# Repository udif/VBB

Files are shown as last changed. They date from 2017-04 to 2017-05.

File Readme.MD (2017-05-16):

VBB - A VCC Breakout Board
==========================
This board is intended as a VCC breakout board. It supports the following features:
* A wide array of connectors: USB A, B, Micro, Mini, DC plug, Banana Plug, screw terminal.
* While GND is always connected among all connectors, D+/D-/VCC are all switchable via pins.
* Banana plug dimensions match the front panel of Arachnid Lab's Re:Load Pro, and can be mounted directly on it, if one wishes.
* USB-A footprint can be soldered with either a male or female USB-A plug.

Possible uses:
--------------
1. Current measurements by inserting the Banana Plugs in the VCC path between any two connectors.
2. Power supply measurements using standard connectors (USB mini, micro, DC barrel jack) with Re:Load Pro 
3. Controlling of USB D+/D-, either disconnecting it to prevent a data connection, or biasing it with resistors to select a specific charging mode. Some Combinations, such as inserting VBB with two USB-A plugs (male+female) may require 2 PCBs.

TBD
---
* Add VCC/GND/D+/D- marks on the bottom side header pins.
* Possibly add mounting holes
* Next revision will be narrow and long, and support two independent USB-A connectors (male+female), one on each side.

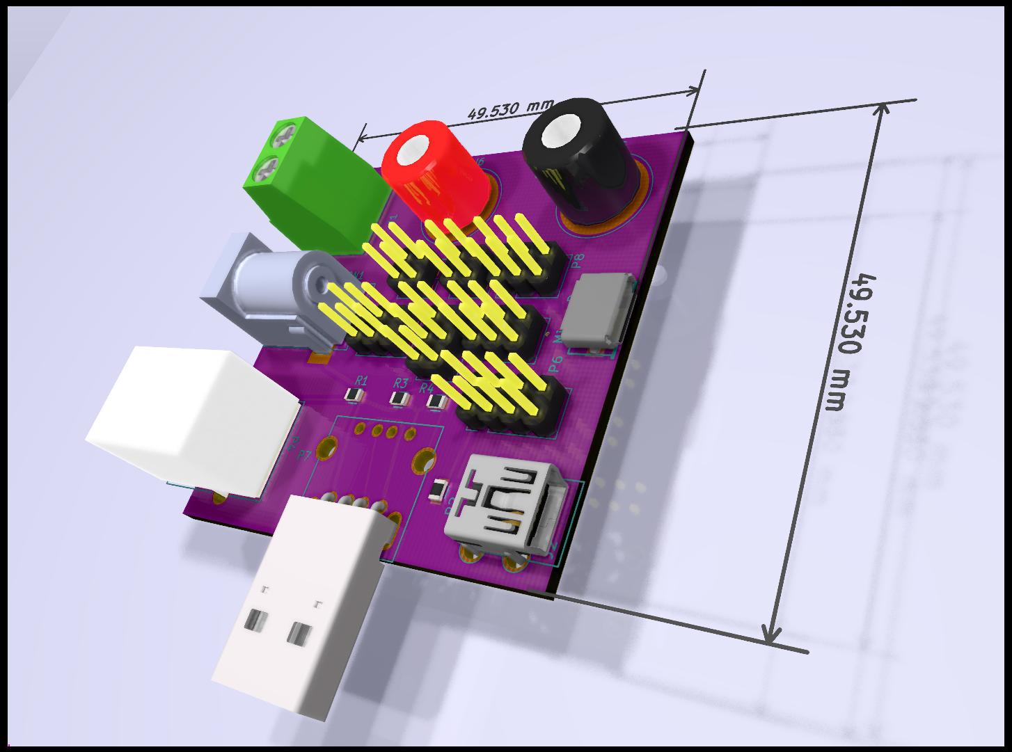
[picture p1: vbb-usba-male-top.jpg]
Top, USB-A Male

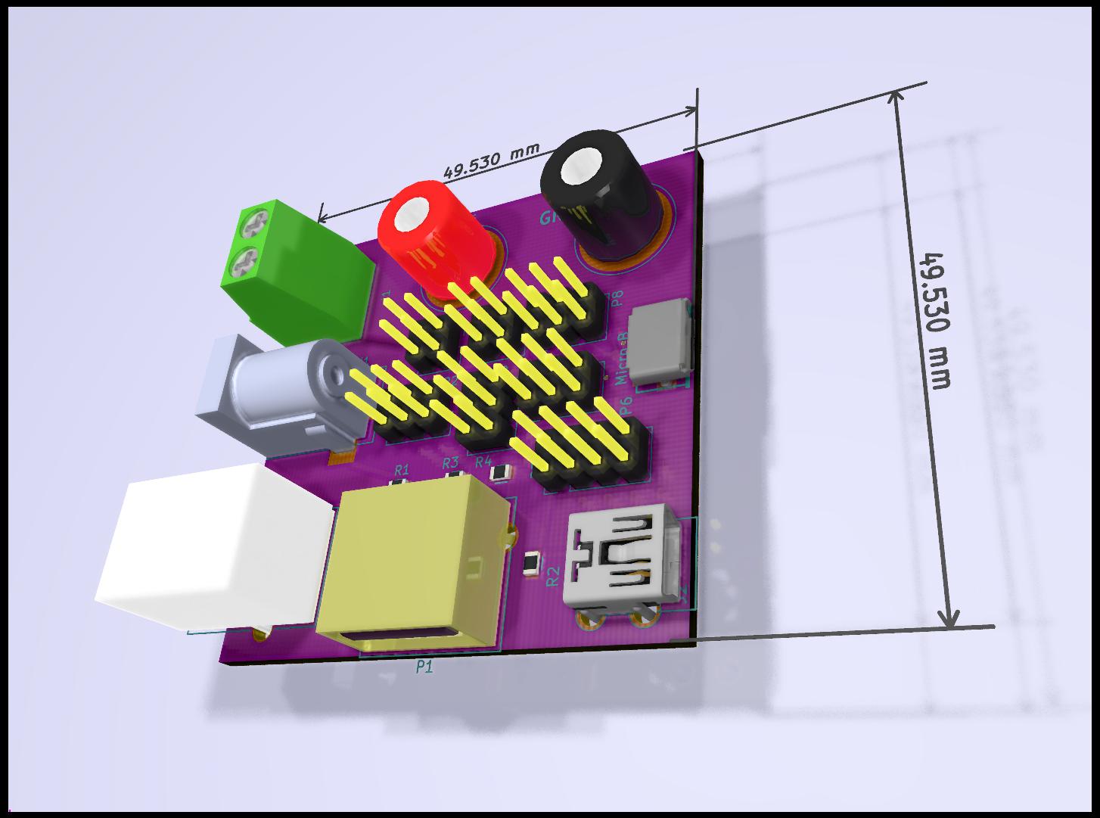
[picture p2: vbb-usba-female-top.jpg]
Top, USB-A Female

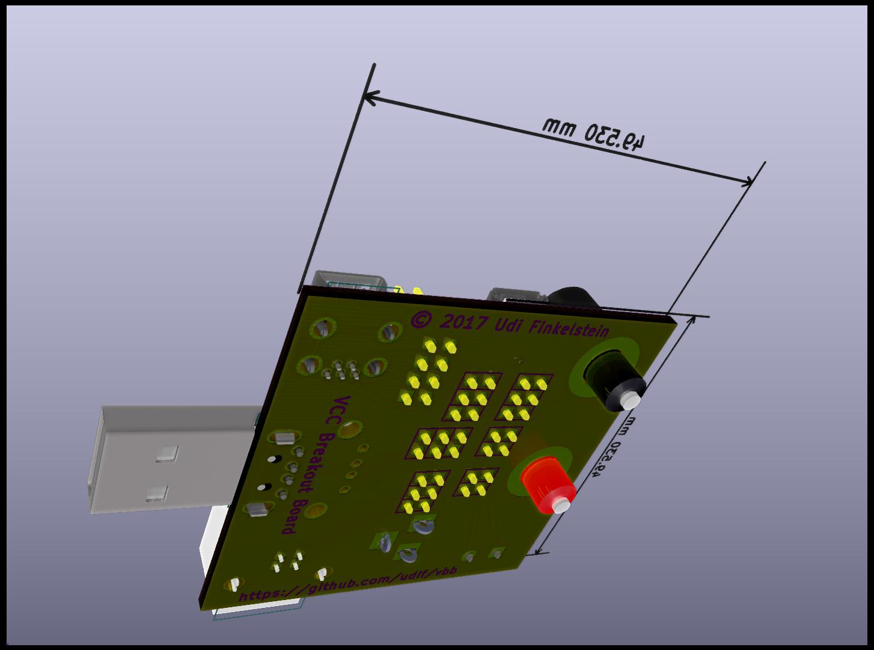
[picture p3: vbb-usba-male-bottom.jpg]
Bottom, USB-A Male

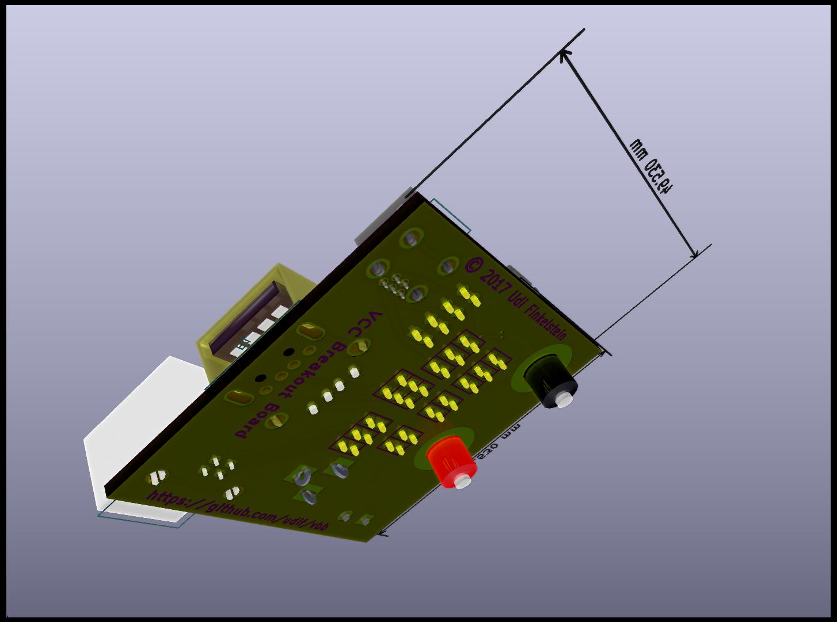
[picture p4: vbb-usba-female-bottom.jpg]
Bottom, USB-A Female

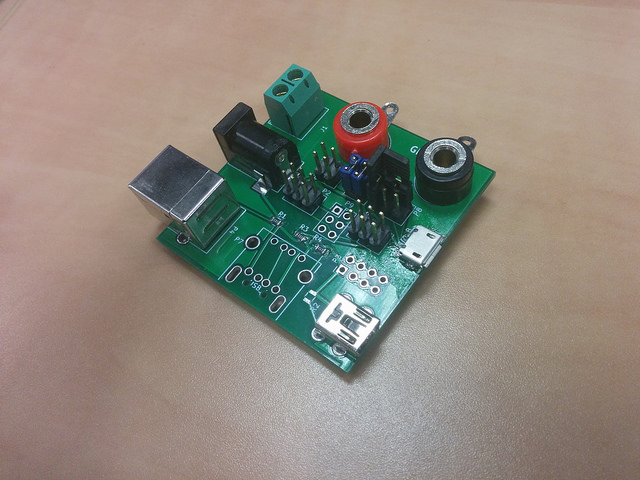
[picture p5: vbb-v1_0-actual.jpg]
Actual board, no USB-A connector soldered


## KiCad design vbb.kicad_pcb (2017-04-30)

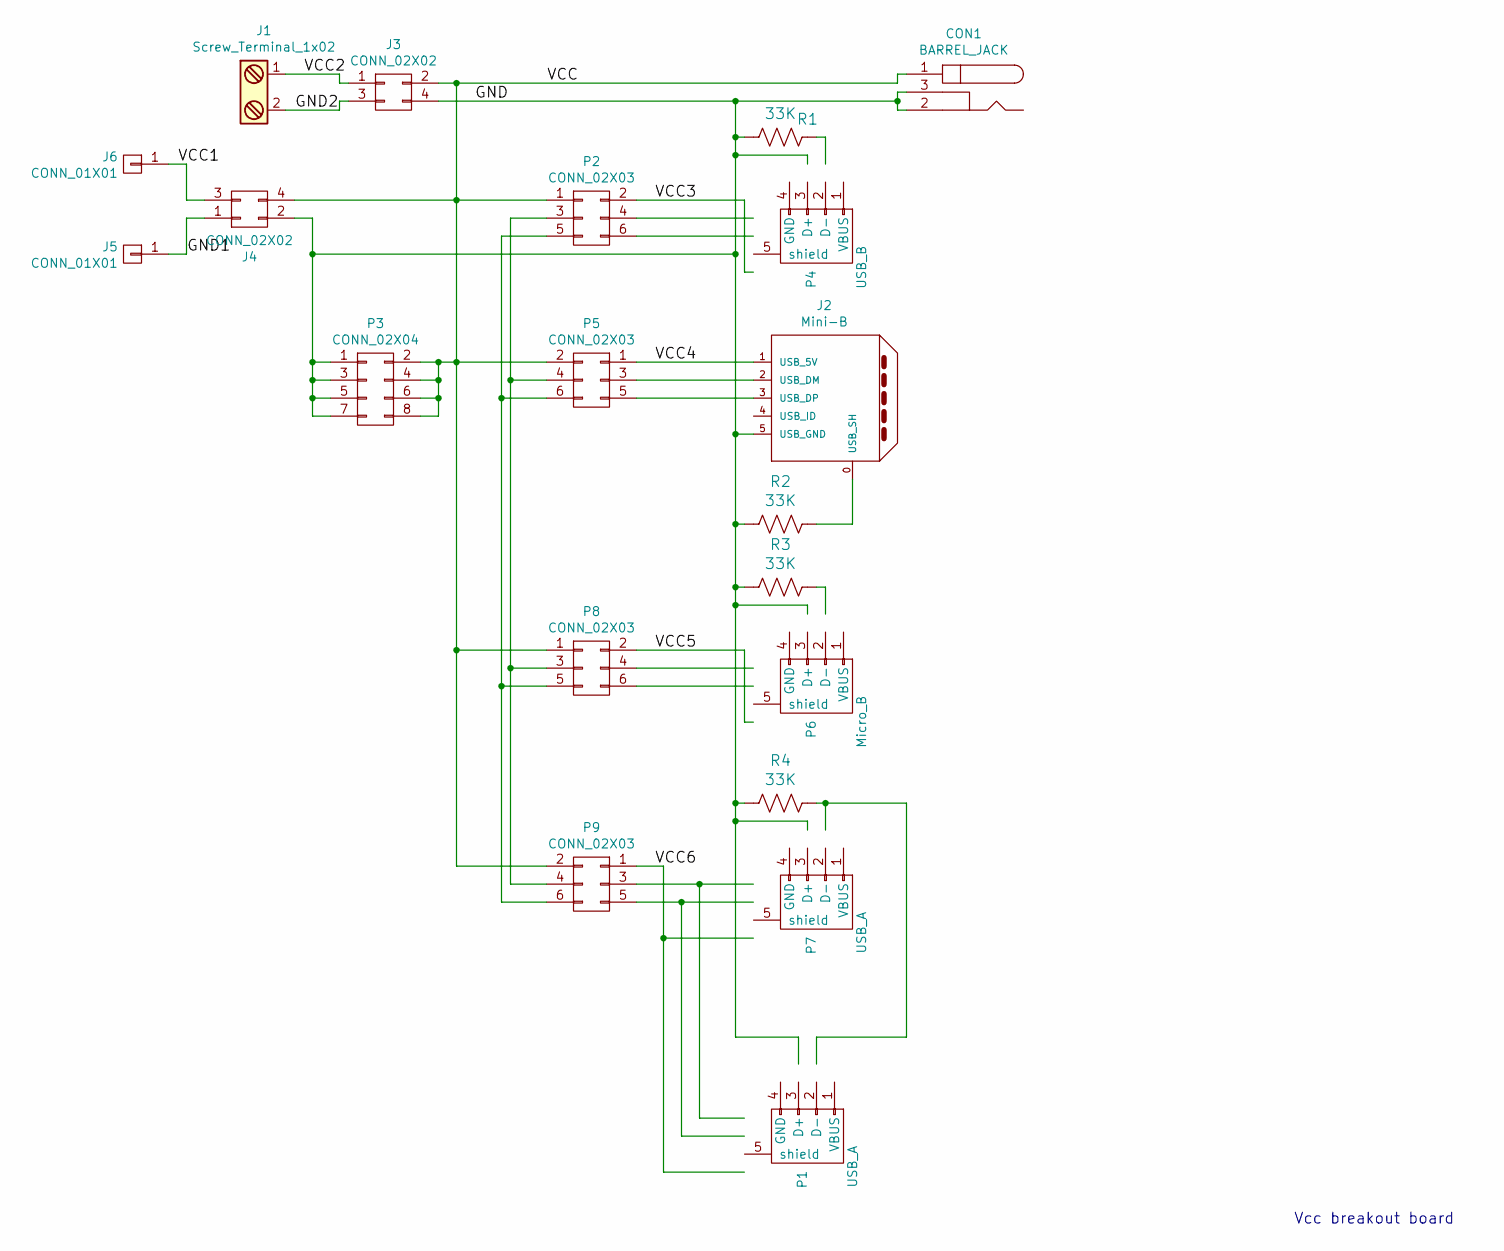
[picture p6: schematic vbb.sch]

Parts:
CON1: BARREL_JACK
J1: Screw_Terminal_1x02; TerminalBlock_Pheonix_MKDS1.5-2pol
J2: Mini-B; XM7D-0512
J3, J4: CONN_02X02; Pin_Header_Straight_2x02_Pitch2.54mm
J5, J6: CONN_01X01; Banana_Jack_1Pin
P1: USB_A; MOLEX-48037-0001
P2, P5, P8, P9: CONN_02X03; Pin_Header_Straight_2x03_Pitch2.54mm
P3: CONN_02X04; Pin_Header_Straight_2x04_Pitch2.54mm
P4: USB_B
P6: Micro_B; conn_usb_B_micro_smd
P7: USB_A
R1, R2, R3, R4: 33K; R_0805

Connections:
/GND: CON1.2, CON1.3, J2.5 (USB_GND), J3.4, J4.2, P1.4 (GND), P3.1, P3.3, P3.5, P3.7, P4.4 (GND), P6.4 (GND), P7.4 (GND), R1.1 (A), R2.1 (A), R3.1 (A), R4.1 (A)
/GND1: J4.1, J5.1
/GND2: J1.2, J3.3
/VCC: CON1.1, J3.2, J4.4, P2.1, P3.2, P3.4, P3.6, P3.8, P5.2, P8.1, P9.2
/VCC1: J4.3, J6.1
/VCC2: J1.1, J3.1
/VCC3: P2.2, P4.1 (VBUS)
/VCC4: J2.1 (USB_5V), P5.1
/VCC5: P6.1 (VBUS), P8.2
/VCC6: P1.1 (VBUS), P7.1 (VBUS), P9.1
unnamed: J2.0 (USB_SH), R2.2 (K)
unnamed: J2.2 (USB_DM), P5.3
unnamed: J2.3 (USB_DP), P5.5
unnamed: P1.2 (D-), P7.2 (D-), P9.3
unnamed: P1.3 (D+), P7.3 (D+), P9.5
unnamed: P1.5 (shield), P7.5 (shield), R4.2 (K)
unnamed: P2.3, P5.4, P8.3, P9.4
unnamed: P2.4, P4.2 (D-)
unnamed: P2.5, P5.6, P8.5, P9.6
unnamed: P2.6, P4.3 (D+)
unnamed: P4.5 (shield), R1.2 (K)
unnamed: P6.2 (D-), P8.4
unnamed: P6.3 (D+), P8.6
unnamed: P6.5 (shield), R3.2 (K)

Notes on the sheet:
Vcc breakout board

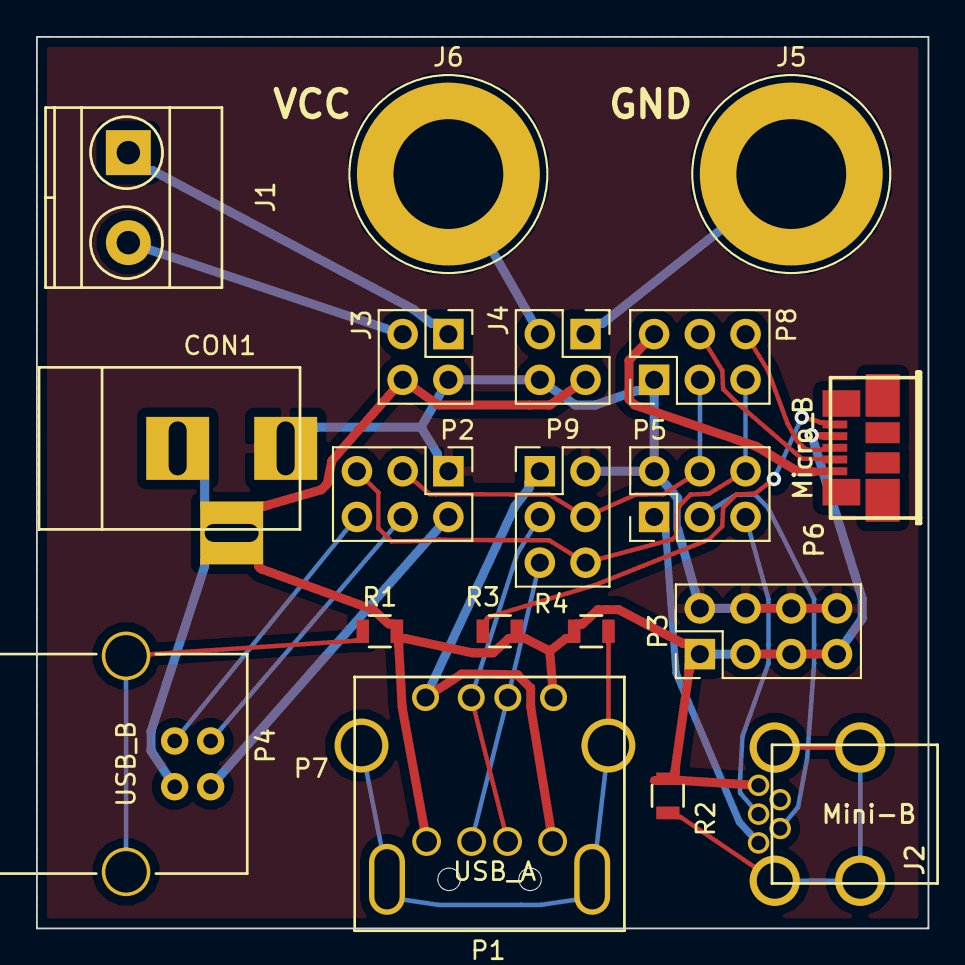
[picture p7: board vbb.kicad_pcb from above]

Board: 2 copper layers, 49.5 x 49.5 mm, 20 parts (0 on the bottom side), 24 nets.

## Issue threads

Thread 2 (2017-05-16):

No drill holes for micro-USB socket

udif, 2017-05-16:
The USB socket has two tiny pins for aligning the connector.
The holes for these pins should be added to the micro-USB footprint.

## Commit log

2016-11-26 Initial version
    [vbb.kicad_pcb, vbb.sch]
2016-11-26 Use Omron XM7D-0512 through hole USB mini connector
    [vbb.sch]
2016-11-27 Replaced old surface mount USB Mini with through hole Omron Mini-USB B through hole XM7D-0512
    [vbb.kicad_pcb]
2016-11-27 Combined separate jumpers into a 2x03 connector As a result, board now fits the 50mmx50mm size group.
    [vbb.kicad_pcb, vbb.sch]
2016-11-29 Added missing ground wire.
    [vbb.sch]
2016-11-29 First pass through TopoR
    [vbb.kicad_pcb]
2017-04-16 Files should be ready: Copper pours on both sides Added jumpers for current measurement Added silkscreen text VCC/GNC tracks are twice as wide.
    [vbb.kicad_pcb, vbb.sch]
2017-04-16 Fixes DRC by changing track-to-track clearance to 0.18mm and by deleting redundant multiple copper pours.
    [vbb.kicad_pcb]
2017-04-21 Final (?) files. Swapped Banana jack pins on both PCB and schematics to have Red VCC, Black GND rendering. No actual layout change. Rearranged references on board Added VCC/GND marks on back side.
    [vbb.kicad_pcb, vbb.sch]
2017-04-21 Is this the final one? I think I haven't saved the schematics
    [vbb.sch]
2017-04-22 1st iteration of gerbers
    [combined.GKO, combined.gbl, combined.gbo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]
2017-04-30 Files as delivered for manufacturing.
    [vbb-B.Cu.gbl, vbb-B.Mask.gbs, vbb-B.Paste.gbp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]
2017-04-30 Added README file and sample images
2017-05-16 Final files as manufactured
    [combined.GKO, combined.gbl, combined.gbo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]
2017-05-16 Update Readme.MD
    Added a picture of the actual board.

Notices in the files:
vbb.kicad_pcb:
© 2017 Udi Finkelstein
